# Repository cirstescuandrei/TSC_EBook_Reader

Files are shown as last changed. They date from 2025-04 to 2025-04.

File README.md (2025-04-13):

# TSC_EBook_Reader

### Cîrstescu Andrei-Vlad 331CC

# Tabletă E-Paper ESP32-C6 – Documentație Hardware

## Descriere Generală

Această tabletă cu afișaj E-Paper este proiectată pentru consum redus de energie și uzabilitate extinsă. 
Se bazează pe ESP32-C6 și include funcționalități precum citire din microSD, senzori de mediu, RTC și 
interacțiune cu utilizatorul prin butoane tactile.

openbook_diagram

# BOM
| Components 	| Links 	|
|---	|---	|
| BOOT_BUTTON, RESET_BUTTON, CANGE_BUTTON 	| https://industry.panasonic.com/global/en/products/control/switch/light-touch/number/evqpuj02k 	|
| C1, C1_BAT, C1_BAT1, C1_BAT2, C2, C2_BAT, C4, C4_USB, C5, C6, C7, C8, C9, C10, C_DELAY,  EPD_C1, EPD_C2, EPD_C5, EPD_C6, EPD_C7, EPD_C8, EPD_C9, EPD_C10, EPD_C11, EPD_C12 	| https://componentsearchengine.com/part-view/CC0402MRX5R5BB106/YAGEO 	|
| C3 	| https://componentsearchengine.com/part-view/TCJB107M002R0055E/Kyocera%20AVX 	|
| C10_SUPERCAP 	| https://www.snapeda.com/parts/CPH3225A/Seiko+Instruments/view-part/?ref=eda 	|
| CHG_LED 	| https://www.snapeda.com/parts/KP-1608SURCK/Kingbright/view-part/?ref=search&t=LED%200603 	|
| D1 	| https://www.snapeda.com/parts/USBLC6-2SC6Y/STMicroelectronics/view-part/?ref=eda 	|
| D2, D7 	| https://eu.mouser.com/ProductDetail/KYOCERA-AVX/SD0805S020S1R0?qs=jCA%252BPfw4LHbpkAoSnwrdjw%3D%3D 	|
| D3, D4, D5 	| https://www.snapeda.com/parts/MBR0530/Onsemi/view-part/?ref=eda 	|
| D6, D8, D9, D10, D11, D12 	| https://www.snapeda.com/parts/PGB1010603MR/Littelfuse/view-part/?ref=eda 	|
| IC1 	| https://componentsearchengine.com/part-view/BD5229G-TR/ROHM%20Semiconductor 	|
| IC4 	| https://componentsearchengine.com/part-view/XC6220A331MR-G/Torex 	|
| J1 	| https://www.mouser.co.uk/ProductDetail/Hirose-Connector/FH34SRJ-24S-0.5SH99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 	|
| J2 	| https://componentsearchengine.com/part-view/USB4110-GF-A/GCT%20(GLOBAL%20CONNECTOR%20TECHNOLOGY 	|
| J3 	| https://www.mouser.co.uk/ProductDetail/Adafruit/4208?qs=PzGy0jfpSMtbScLbr0L5dw%3D%3D 	|
| J4 	| https://store.comet.srl.ro/Catalogue/Product/43497/ 	|
| L1 	| https://eu.mouser.com/ProductDetail/Wurth-Elektronik/744043680?qs=PGXP4M47uW6VkZq%252BkzjrHA%3D%3D 	|
| PFMF.050.1 	| https://www.mouser.co.uk/ProductDetail/EPCOS-TDK/B72520T0350K062?qs=dEfas%2FXlABIszF52uu7vrg%3D%3D 	|
| Q1, Q2 	| https://componentsearchengine.com/part-view/DMG2305UX-7/Diodes%20Incorporated 	|
| Q3 	| https://componentsearchengine.com/part-view/SI1308EDL-T1-GE3/Vishay_ 	|
| R1, R1-PINH, R1-PINH1, R1_BAT, R1_PWRUSB, R2, R2-PINH, R2-PINH1, R2-USB, R2-USB1, R2_BAT, R3, R4, R5, R6, R7, R8, R9, 10, R_BOOT, R_CAPACITOR, R_CHANGE, R_CL1, R_RESET 	| https://componentsearchengine.com/part-view/R0402%201%25%20100%20K%20(RC0402FR-07100KL)/YAGEO 	|
| SENSOR2 	| https://www.snapeda.com/parts/BME680/Bosch/view-part/?welcome=home 	|
| SJ1 	| https://grabcad.com/library/solder-jumpers-1 	|
| TP 	| - 	|
| U1 	| https://www.snapeda.com/parts/W25Q512JVEIQ/Winbond+Electronics/view-part/?ref=eda 	|
| U2 	| https://www.snapeda.com/parts/ESP32-C6-WROOM-1-N8/Espressif+Systems/view-part/?ref=eda 	|
| U3 	| https://www.snapeda.com/parts/DS3231SN%23/Analog+Devices/view-part/?ref=eda 	|
| U4 	| https://www.snapeda.com/parts/MAX17048G+T10/Analog+Devices/view-part/?ref=eda 	|
| U5 	| https://www.mouser.co.uk/ProductDetail/Microchip-Technology/MCP73831T-5ACI-OT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 	|

---

## Componente Principale

### ESP32-C6-WROOM-1-N8
- Control total: afișaj, senzori, memorie
- Protocoale: SPI, I²C, UART, USB 2.0
- Consum: ~130 mA activ / ~12 µA deep sleep

### Afișaj E-Paper 7.5” (800x480 px)
- SPI + GPIO: BUSY, DC, RST, CS
- Consum 0 mA idle, ~26 mA la refresh
- Perfect pentru afișare statică de lungă durată

### Memorie
- **W25Q512 NOR Flash** (64MB, SPI) – firmware & cărți
- **MicroSD Card** (SPI partajat) – fișiere externe

### RTC – DS3231SN
- I²C + GPIO (INT, RST)
- Timp real precis, funcțional și în sleep
- Suportă trezirea automată

### Senzor Ambiental – BME680
- Temperatură, umiditate, presiune, compuși volatili
- I²C partajat cu RTC
- Consum redus: ~2.1 mA activ

### Alimentare
- **Baterie Li-Po 2500 mAh**
- **Încărcare USB-C** cu MCP73831 (max 1A)
- **LDO XC6220** – 3.3V stabil pentru sistem
- Monitorizare baterie prin MAX17048 (ADC pe IO18)
- LED încărcare controlat de IO4

### USB-C & Protecție
- Protocol: USB 2.0 + VBUS
- Programare + alimentare
- Protecție ESD integrată

### Interfață Utilizator
- 3 butoane tactile: BOOT (IO15), RESET (IO3), CHANGE (IO23)
- LED stare încărcare (IO4)

### Extensii
- **Qwiic/Stemma QT**: senzori I²C plug & play (IO19/IO20)
- GPIO suplimentari disponibili

---

## Pinout ESP32-C6

| Pin ESP32 | Funcție | Periferic |
|---|---|---|
| IO2 | MISO (SPI) | Flash, SD, E-Paper  |
| IO6 | SCK (SPI) | Flash, SD, E-Paper  |
| IO7 | MOSI (SPI) | Flash, SD, E-Paper  |
| IO12 | CS Flash | Memorie NOR |
| IO10 | CS E-Paper | Display |
| IO4 | CS SD | microSD |
| IO5 | DC E-Paper | Display |
| IO14 | BUSY E-Paper  | Display |
| IO21 | RST E-Paper | Display |
| IO19/20 | SDA/SCL (I²C) | RTC, BME680, Qwiic  |
| IO0 | INT RTC | RTC Wake |
| IO17 | RTC RST | RTC Reset |
| IO18 | ADC Battery | Monitorizare |
| IO15 | BOOT | Buton BOOT |
| IO3 | RESET | Buton RESET |
| IO23 | CHANGE | Buton navigare |
| IO25/24 | UART TX/RX | Debug Serial |

---

## Estimare Consum

| Modul | Activ | Idle / Sleep |
|---|---|---|
| ESP32-C6 | ~130 mA | ~12 µA |
| E-Paper | ~26 mA | 0 mA |
| BME680 | ~2.1 mA | 0.15 mA |
| microSD | 30–100 mA | ~0.1 mA |
| RTC | ~1 µA | - |
| LED | max 10 mA | - |

### Durată estimată cu baterie 2500 mAh
- Utilizare activă: **8–10 ore**
- Standby / Deep sleep: **până la 300 zile**

---

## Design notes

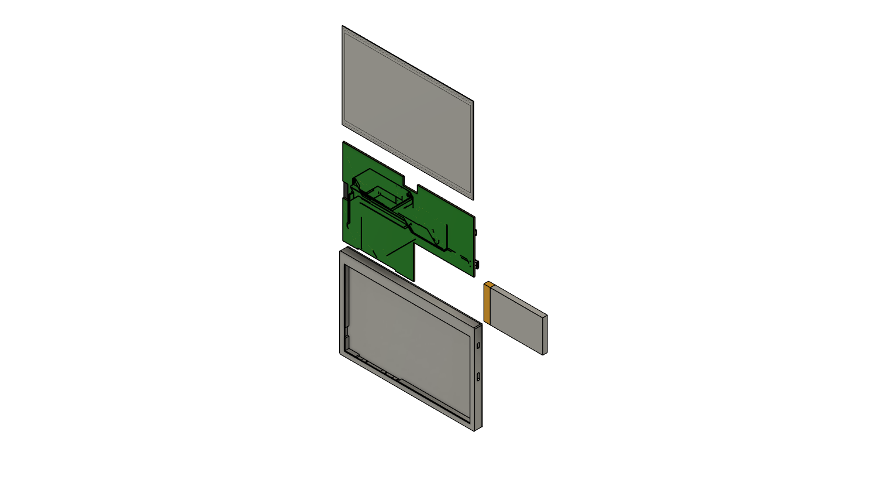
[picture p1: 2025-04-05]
Images/OpenBook_3D_Model_Exploded.png

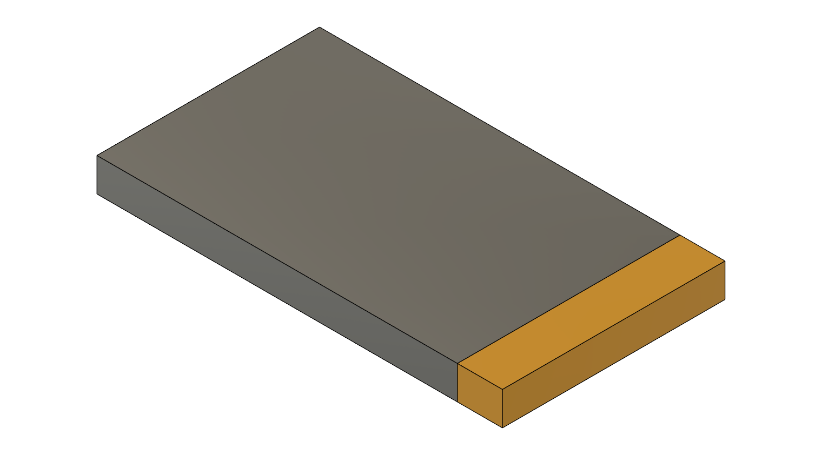
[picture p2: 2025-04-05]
Images/Battery.png

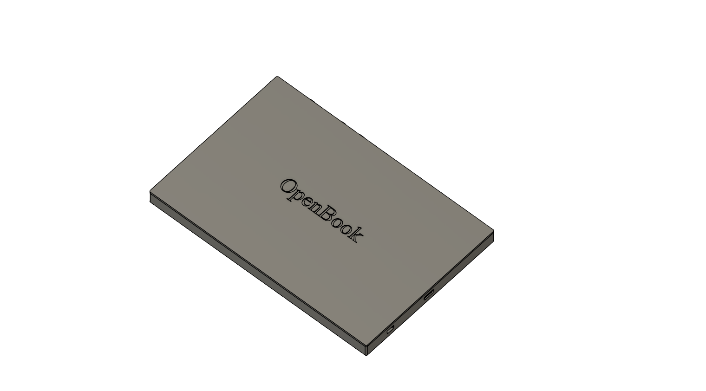
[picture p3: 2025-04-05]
Images/OpenBook_3D_Model.png

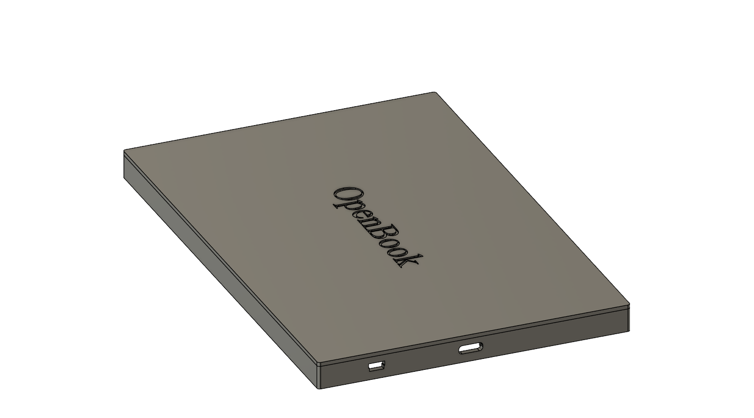
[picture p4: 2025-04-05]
Images/OpenBook Enclosure.png

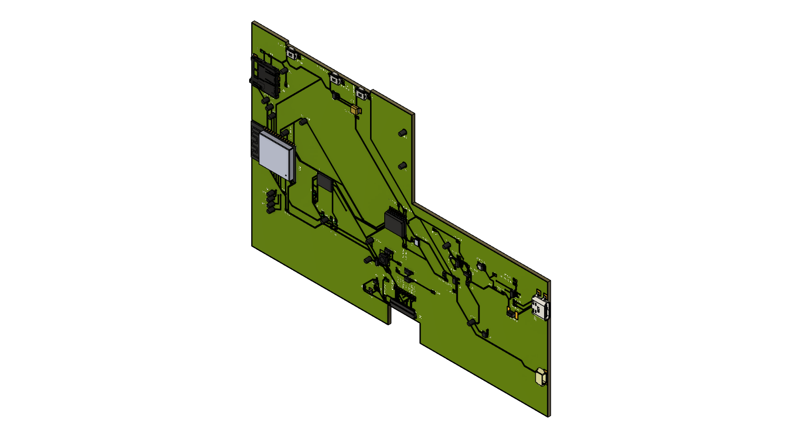
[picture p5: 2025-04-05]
Images/PCB.png

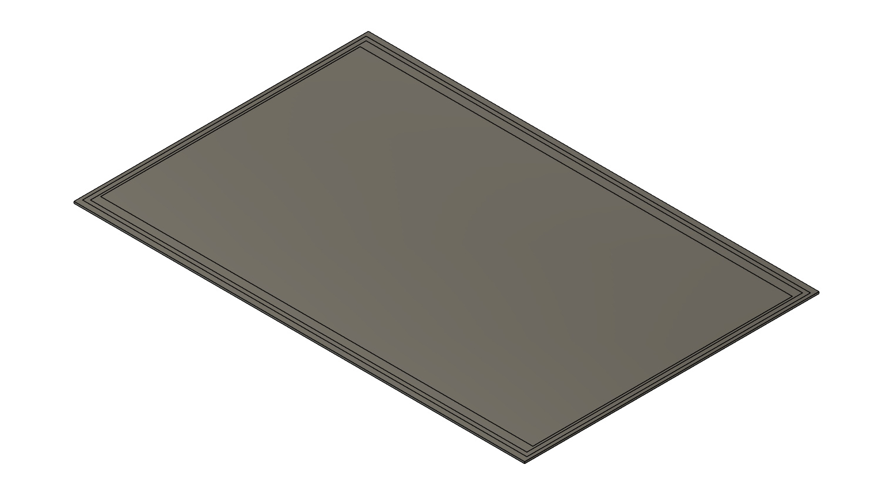
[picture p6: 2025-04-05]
Images/Display.png

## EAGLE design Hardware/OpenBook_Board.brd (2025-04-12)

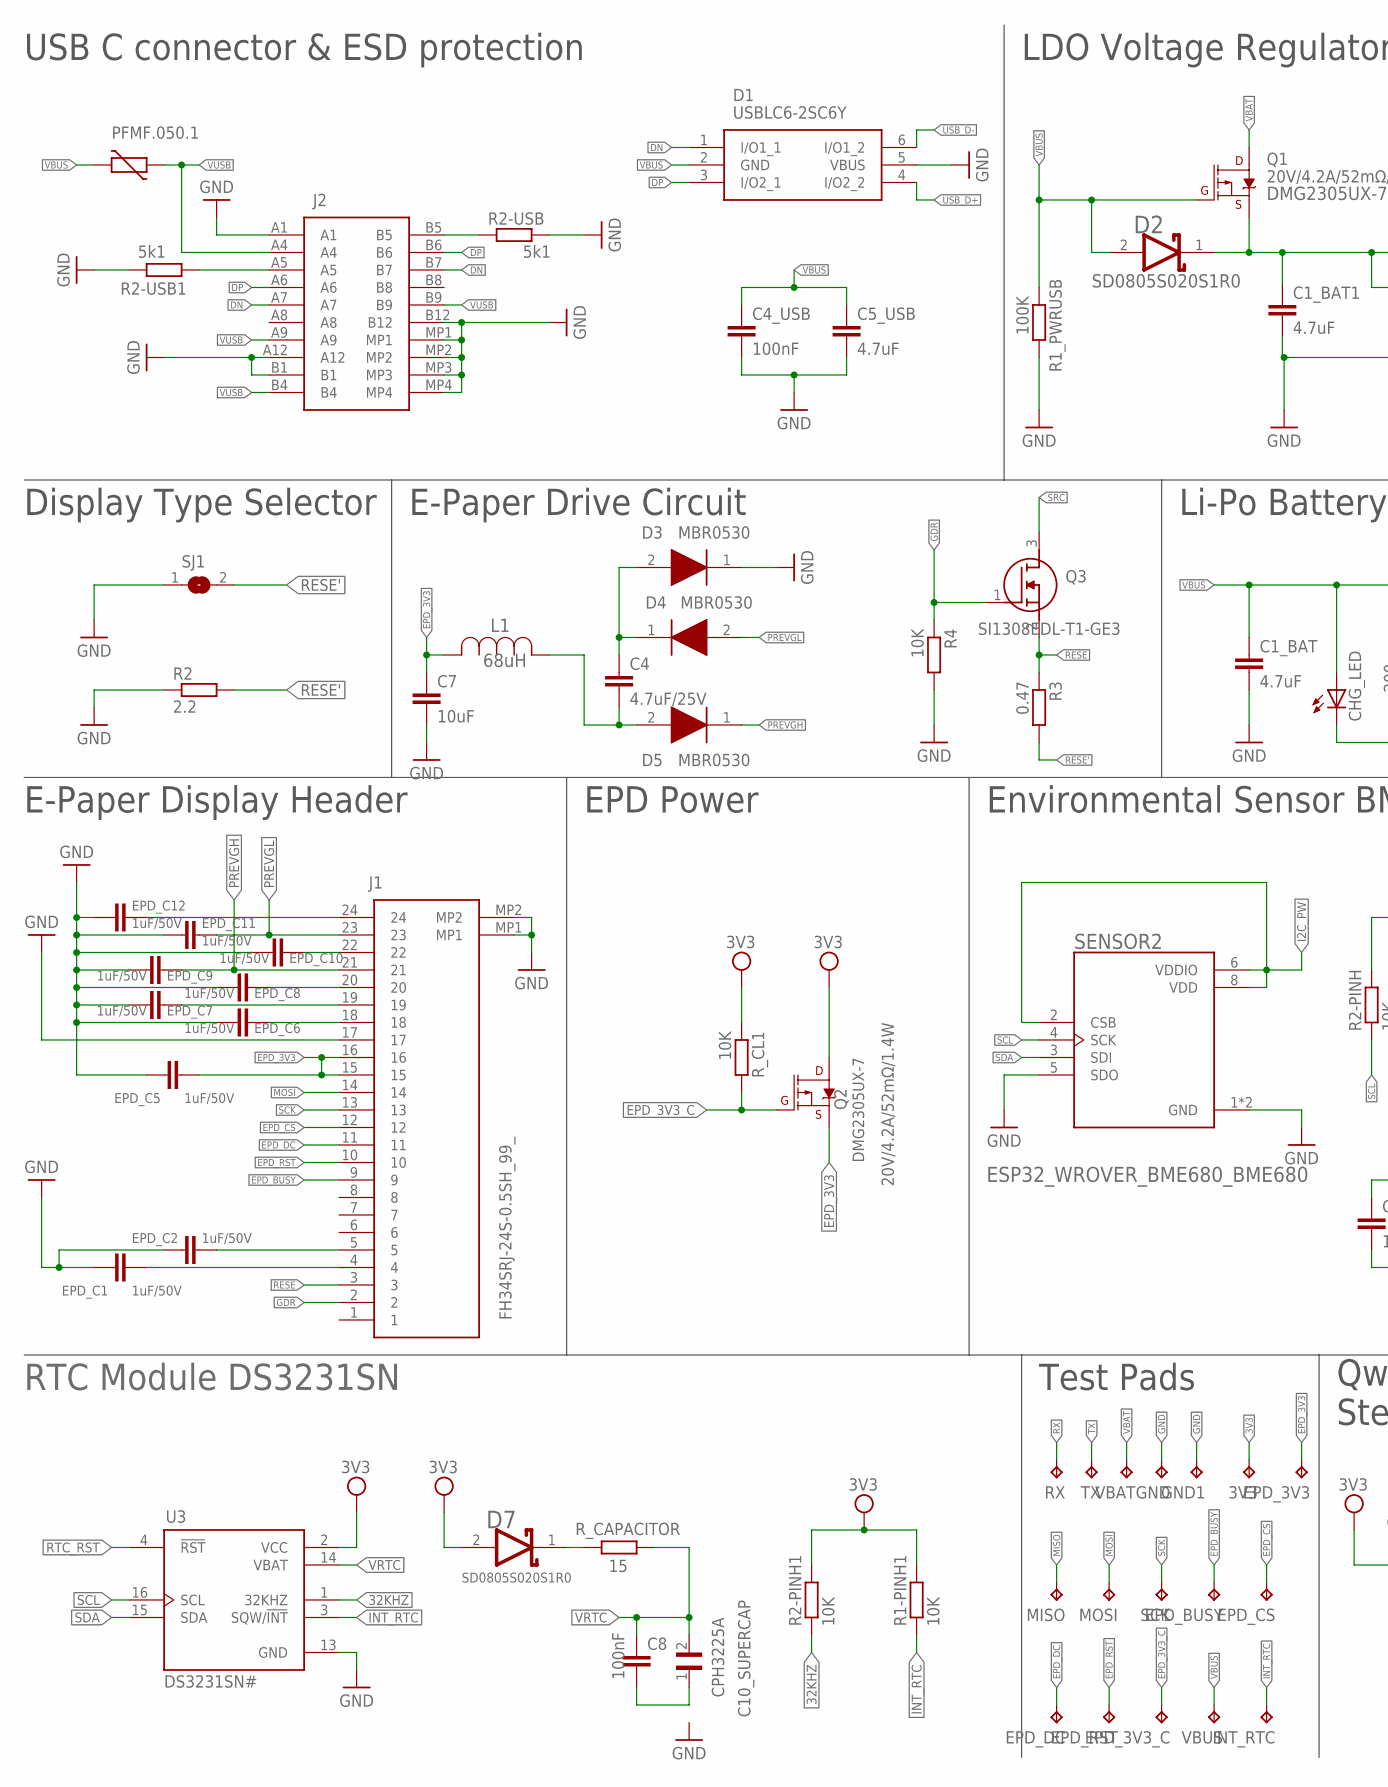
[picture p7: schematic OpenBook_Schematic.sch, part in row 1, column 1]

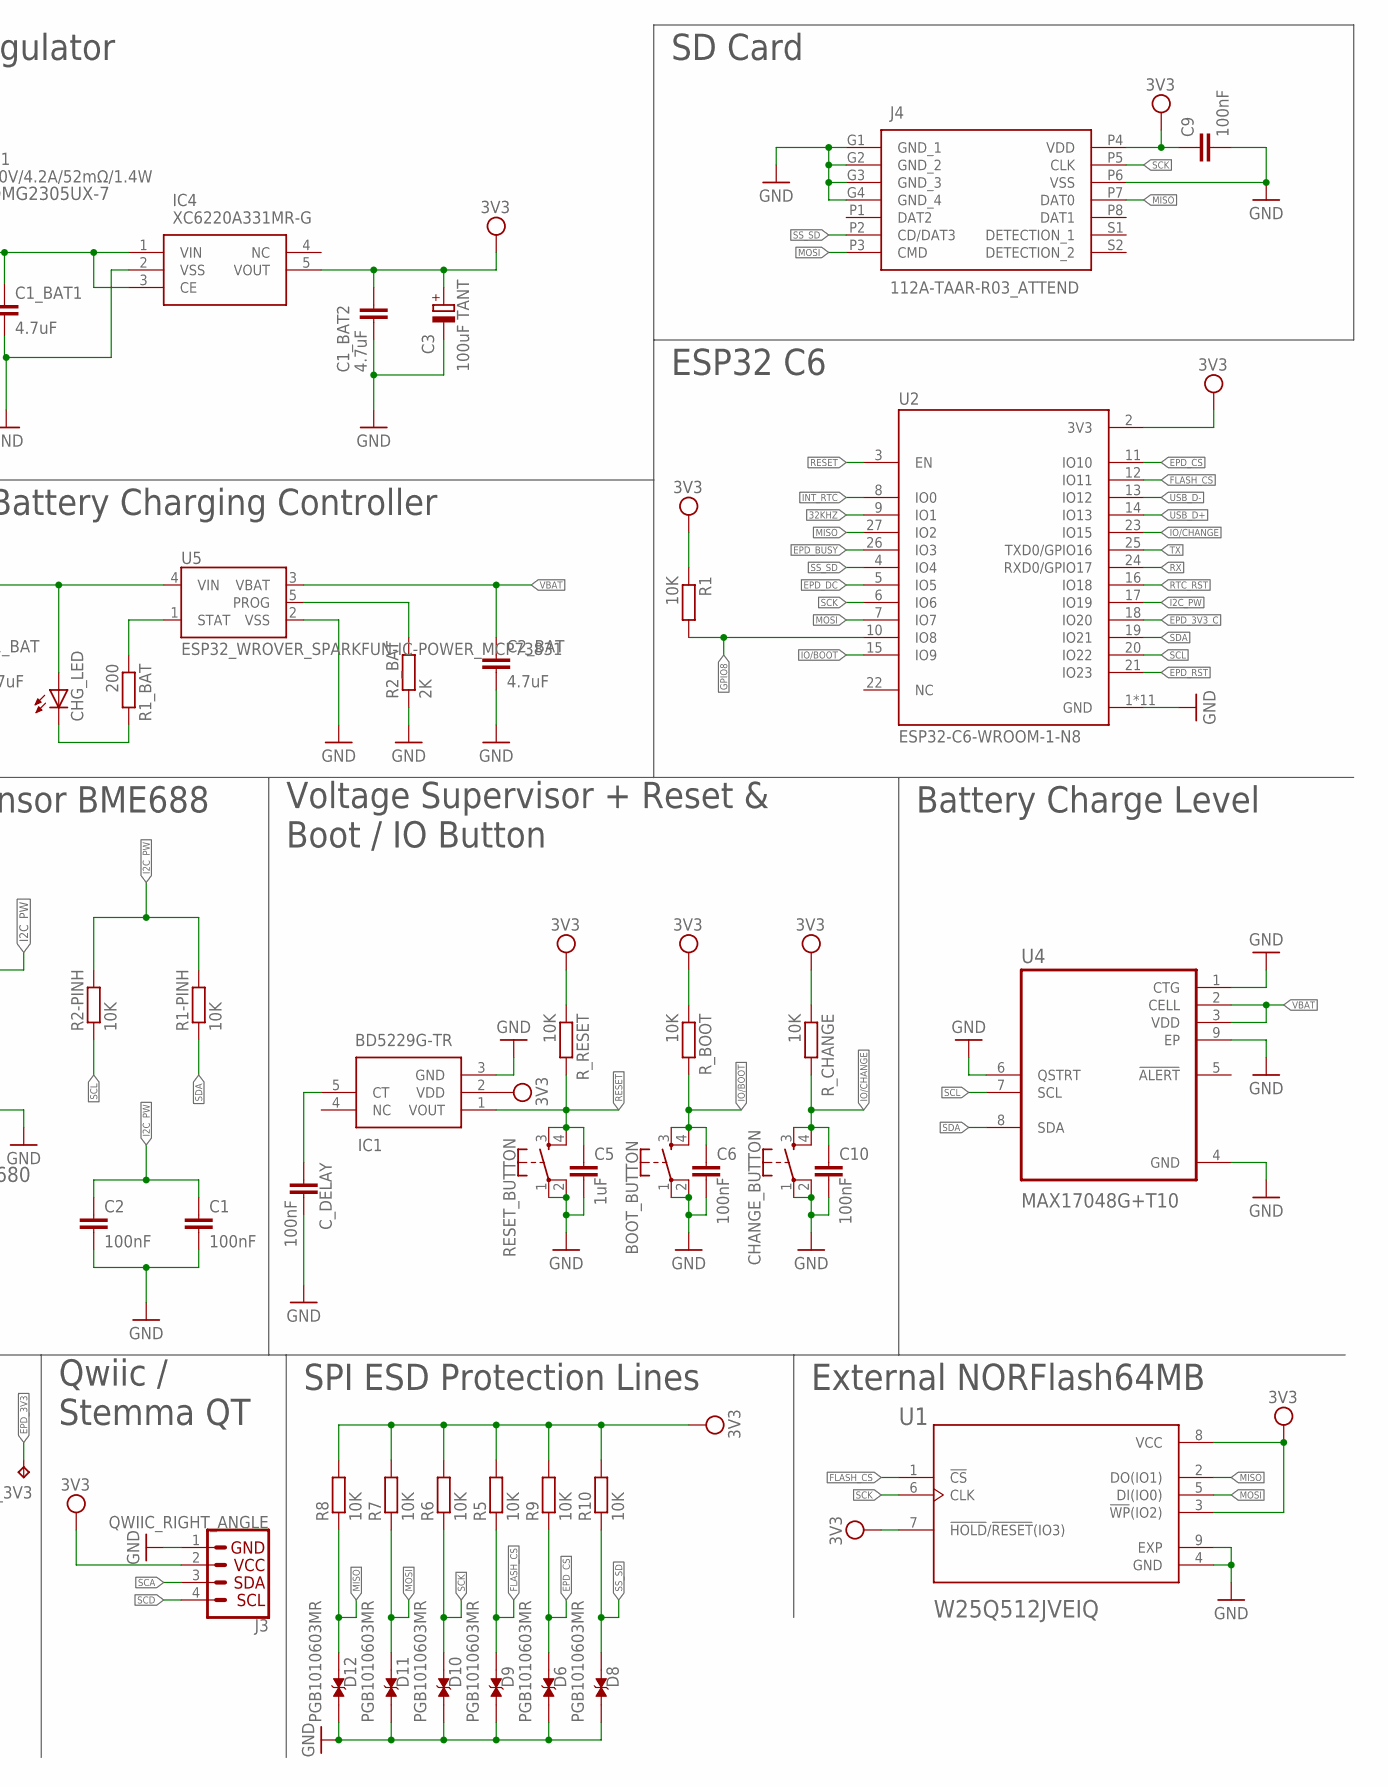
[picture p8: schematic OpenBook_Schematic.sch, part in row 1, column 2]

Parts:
3V3: TPTP20R; TP20R
BOOT_BUTTON: BUTTON_CUSYOMV1BUTTON; MYBUTTON
C1, C2, C9: 100nF; ESP32_WROVER_EAGLE-LTSPICE_C0402
C1_BAT, C1_BAT1, C1_BAT2, C2_BAT, C5_USB: 4.7uF; EAGLE-LTSPICE_C0402
C3: 100uF TANT; RCL_CT3528
C4: 4.7uF/25V; EAGLE-LTSPICE_C0402
C4_USB, C6, C8, C10: 100nF; EAGLE-LTSPICE_C0402
C5: 1uF; EAGLE-LTSPICE_C0402
C7: 10uF; EAGLE-LTSPICE_C0402
C10_SUPERCAP: CPH3225A; CAPCP3225X100N
CHANGE_BUTTON: BUTTON_CUSYOMV1BUTTON; MYBUTTON
CHG_LED: ADAFRUIT_LEDCHIP-LED0603; ADAFRUIT_CHIP-LED0603
C_DELAY: 100nF; ESP32_WROVER_EAGLE-LTSPICE_C0402
D1: USBLC6-2SC6Y; SOT95P280X145-6N
D2, D7: ESP32_WROVER_AVX---SD0805S020S1R0_AVX_SD0805S020S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; ESP32_WROVER_AVX---SD0805S020S1R0_AVX_SD0805S020S1R0_0
D3, D4, D5: MBR0530; SOD3716X135N
D6, D8, D9, D10, D11, D12: PGB1010603MR; DIOC1608X36N
EPD_3V3, EPD_3V3_C: TPTP20R; TP20R
EPD_BUSY: TPTP20R; TP20R
EPD_C1, EPD_C2, EPD_C5, EPD_C6, EPD_C7, EPD_C8, EPD_C9, EPD_C10, EPD_C11, EPD_C12: 1uF/50V; ESP32_WROVER_EAGLE-LTSPICE_C0402
EPD_CS: TPTP20R; TP20R
EPD_DC: TPTP20R; TP20R
EPD_RST: TPTP20R; TP20R
GND, GND1: TPTP20R; TP20R
IC1: BD5229G-TR; SOT95P280X125-5N
IC4: XC6220A331MR-G; SOT95P280X120-5N
INT_RTC: TPTP20R; TP20R
J1: FH34SRJ-24S-0.5SH_99_; FH34SRJ24S05SH99
J2: SAMACSYS_PARTS_USB4110-GF-A; SAMACSYS_PARTS_USB4110GFA
J3: QWIIC_RIGHT_ANGLE; JST04_1MM_RA
J4: 112A-TAAR-R03_ATTEND; 112ATAARR03ATTEND
L1: 68uH; IND_4828-WE-TPC_WRE
MISO: TPTP20R; TP20R
MOSI: TPTP20R; TP20R
PFMF.050.1: ESP32C6_VARISTORCN1812; ESP32C6_VARISTOR_CT/CN1812
Q1, Q2: 20V/4.2A/52mΩ/1.4W; ESP32_WROVER_SPARKFUN-DISCRETESEMI_SOT23-3
Q3: SI1308EDL-T1-GE3; SOT65P210X110-3N
R1, R1-PINH, R1-PINH1, R2-PINH, R2-PINH1, R4, R5, R6, R7, R8, R9, R10: 10K; ESP32_WROVER_EAGLE-LTSPICE_R0402
R1_BAT: 200; ESP32_WROVER_EAGLE-LTSPICE_R0402
R1_PWRUSB: 100K; ESP32_WROVER_EAGLE-LTSPICE_R0402
R2: 2.2; ESP32_WROVER_EAGLE-LTSPICE_R0402
R2-USB, R2-USB1: 5k1; ESP32_WROVER_EAGLE-LTSPICE_R0402
R2_BAT: 2K; ESP32_WROVER_EAGLE-LTSPICE_R0402
R3: 0.47; ESP32_WROVER_EAGLE-LTSPICE_R0402
RESET_BUTTON: BUTTON_CUSYOMV1BUTTON; MYBUTTON
RX: TPTP20R; TP20R
R_BOOT: 10K; ESP32_WROVER_EAGLE-LTSPICE_R0402
R_CAPACITOR: 15; ESP32_WROVER_EAGLE-LTSPICE_R0402
R_CHANGE: 10K; ESP32_WROVER_EAGLE-LTSPICE_R0402
R_CL1: 10K; ESP32_WROVER_EAGLE-LTSPICE_R0402
R_RESET: 10K; ESP32_WROVER_EAGLE-LTSPICE_R0402
SCK: TPTP20R; TP20R
SENSOR2: ESP32_WROVER_BME680_BME680; ESP32_WROVER_BME680_PSON80P300X300X100-8N
SJ1: SJ
TX: TPTP20R; TP20R
U1: W25Q512JVEIQ; SON127P600X800X80-9N
U2: ESP32-C6-WROOM-1-N8; XCVR_ESP32-C6-WROOM-1-N8
U3: DS3231SN#; SOIC127P1032X265-16N
U4: MAX17048G+T10; SON50P200X200X80-9N
U5: ESP32_WROVER_SPARKFUN-IC-POWER_MCP73831; ESP32_WROVER_SPARKFUN-IC-POWER_SOT23-5
VBAT: TPTP20R; TP20R
VBUS: TPTP20R; TP20R

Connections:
3V3: 3V3.TP, C1_BAT2.1, C3.+, C9.1, D7.2 (ANODE), IC1.2 (VDD), IC4.5 (VOUT), J3.2, J4.P4 (VDD), Q2.3 (D), R1.1, R1-PINH1.2, R2-PINH1.2, R5.2, R6.2, R7.2, R8.2, R9.2, R10.2, R_BOOT.1, R_CHANGE.1, R_CL1.1, R_RESET.1, U1.3 (!WP!(IO2)), U1.7 (!HOLD!/!RESET!(IO3)), U1.8 (VCC), U2.2 (3V3), U3.2 (VCC)
32KHZ: R2-PINH1.1, U2.9 (IO1), U3.1 (32KHZ)
DN: D1.1 (I/O1_1), J2.A7, J2.B7
DP: D1.3 (I/O2_1), J2.A6, J2.B6
EPD_3V3: C7.1, EPD_3V3.TP, EPD_C5.1, J1.15, J1.16, L1.2, Q2.2 (S)
EPD_3V3_C: EPD_3V3_C.TP, Q2.1 (G), R_CL1.2, U2.18 (IO20)
EPD_BUSY: EPD_BUSY.TP, J1.9, U2.26 (IO3)
EPD_CS: D6.2, EPD_CS.TP, J1.12, R9.1, U2.11 (IO10)
EPD_DC: EPD_DC.TP, J1.11, U2.5 (IO5)
EPD_RST: EPD_RST.TP, J1.10, U2.21 (IO23)
FLASH_CS: D9.2, R5.1, U1.1 (!CS), U2.12 (IO11)
GDR: J1.2, Q3.1 (G), R4.1
GND: BOOT_BUTTON.1, BOOT_BUTTON.2, C1.2, C1_BAT.2, C1_BAT1.2, C1_BAT2.2, C2.2, C2_BAT.2, C3.-, C4_USB.2, C5.2, C5_USB.2, C6.2, C7.2, C9.2, C10.2, CHANGE_BUTTON.1, CHANGE_BUTTON.2, C_DELAY.2, D1.5 (VBUS), D3.1 (K), D6.1, D8.1, D9.1, D10.1, D11.1, D12.1, EPD_C1.2, EPD_C2.2, EPD_C5.2, EPD_C6.2, EPD_C7.2, EPD_C8.2, EPD_C9.2, EPD_C10.2, EPD_C11.2, EPD_C12.2, GND.TP, GND1.TP, IC1.3 (GND), IC4.2 (VSS), J1.17, J1.MP1, J1.MP2, J2.A1, J2.A12, J2.B1, J2.B12, J2.MP1, J2.MP2, J2.MP3, J2.MP4, J3.1, J4.G1 (GND_1), J4.G2 (GND_2), J4.G3 (GND_3), J4.G4 (GND_4), J4.P6 (VSS), R1_PWRUSB.2, R2.1, R2-USB.2, R2-USB1.1, R2_BAT.1, R4.2, RESET_BUTTON.1, RESET_BUTTON.2, SENSOR2.1 (GND), SENSOR2.5 (SDO), SENSOR2.7 (GND), SJ1.1, U1.4 (GND), U1.9 (EXP), U2.1 (GND), U2.28 (GND), U2.29_1 (GND), U2.29_2 (GND), U2.29_3 (GND), U2.29_4 (GND), U2.29_5 (GND), U2.29_6 (GND), U2.29_7 (GND), U2.29_8 (GND), U2.29_9 (GND), U3.13 (GND), U4.1 (CTG), U4.4 (GND), U4.6 (QSTRT), U4.9 (EP), U5.2 (VSS)
GPIO8: R1.2, U2.10 (IO8)
I2C_PW: C1.1, C2.1, R1-PINH.2, R2-PINH.2, SENSOR2.2 (CSB), SENSOR2.6 (VDDIO), SENSOR2.8 (VDD), U2.17 (IO19)
INT_RTC: INT_RTC.TP, R1-PINH1.1, U2.8 (IO0), U3.3 (SQW/!INT)
IO/BOOT: BOOT_BUTTON.3, BOOT_BUTTON.4, C6.1, R_BOOT.2, U2.15 (IO9)
IO/CHANGE: C10.1, CHANGE_BUTTON.3, CHANGE_BUTTON.4, R_CHANGE.2, U2.23 (IO15)
MISO: D12.2, J4.P7 (DAT0), MISO.TP, R8.1, U1.2 (DO(IO1)), U2.27 (IO2)
MOSI: D11.2, J1.14, J4.P3 (CMD), MOSI.TP, R7.1, U1.5 (DI(IO0)), U2.7 (IO7)
unnamed: D7.1 (CATHODE), R_CAPACITOR.2
unnamed: EPD_C2.1, J1.5
unnamed: C8.2, C10_SUPERCAP.1
unnamed: EPD_C1.1, J1.4
unnamed: EPD_C6.1, J1.18
unnamed: EPD_C7.1, J1.19
unnamed: C_DELAY.1, IC1.5 (CT)
unnamed: C4.2, D5.2 (A), L1.1
unnamed: EPD_C8.1, J1.20
unnamed: C4.1, D3.2 (A), D4.1 (K)
unnamed: EPD_C10.1, J1.22
unnamed: EPD_C12.1, J1.24
unnamed: CHG_LED.C, R1_BAT.2
unnamed: R1_BAT.1, U5.1 (STAT)
unnamed: R2_BAT.2, U5.5 (PROG)
unnamed: C1_BAT1.1, D2.1 (CATHODE), IC4.1 (VIN), IC4.3 (CE), Q1.2 (S)
unnamed: J2.A5, R2-USB1.2
unnamed: J2.B5, R2-USB.1
PREVGH: D5.1 (K), EPD_C9.1, J1.21
PREVGL: D4.2 (A), EPD_C11.1, J1.23
RESE: J1.3, Q3.2 (S), R3.1
RESE': R2.2, R3.2, SJ1.2
RESET: C5.1, IC1.1 (VOUT), RESET_BUTTON.3, RESET_BUTTON.4, R_RESET.2, U2.3 (EN)
RTC_RST: U2.16 (IO18), U3.4 (!RST)
RX: RX.TP, U2.24 (RXD0/GPIO17)
SCA: J3.3
SCD: J3.4
SCK: D10.2, J1.13, J4.P5 (CLK), R6.1, SCK.TP, U1.6 (CLK), U2.6 (IO6)
SCL: R2-PINH.1, SENSOR2.4 (SCK), U2.20 (IO22), U3.16 (SCL), U4.7 (SCL)
SDA: R1-PINH.1, SENSOR2.3 (SDI), U2.19 (IO21), U3.15 (SDA), U4.8 (SDA)
SRC: Q3.3 (D)
SS_SD: D8.2, J4.P2 (CD/DAT3), R10.1, U2.4 (IO4)
TX: TX.TP, U2.25 (TXD0/GPIO16)
USB_D+: D1.4 (I/O2_2), U2.14 (IO13)
USB_D-: D1.6 (I/O1_2), U2.13 (IO12)
VBAT: C2_BAT.1, Q1.3 (D), U4.2 (CELL), U4.3 (VDD), U5.3 (VBAT), VBAT.TP
VBUS: C1_BAT.1, C4_USB.1, C5_USB.1, CHG_LED.A, D1.2 (GND), D2.2 (ANODE), PFMF.050.1.2, Q1.1 (G), R1_PWRUSB.1, U5.4 (VIN), VBUS.TP
VRTC: C8.1, C10_SUPERCAP.2, R_CAPACITOR.1, U3.14 (VBAT)
VUSB: J2.A4, J2.A9, J2.B4, J2.B9, PFMF.050.1.1

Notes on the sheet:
SD0805S020S1R0
RTC Module DS3231SN
Test Pads
Qwiic / Stemma QT
SPI ESD Protection Lines
External NORFlash64MB
EPD Power
DMG2305UX-7
E-Paper Display Header
Environmental Sensor BME688
Voltage Supervisor + Reset & Boot / IO Button
Battery Charge Level
Display Type Selector
E-Paper Drive Circuit
Li-Po Battery Charging Controller
ESP32 C6
SD Card
LDO Voltage Regulator
USB C connector & ESD protection

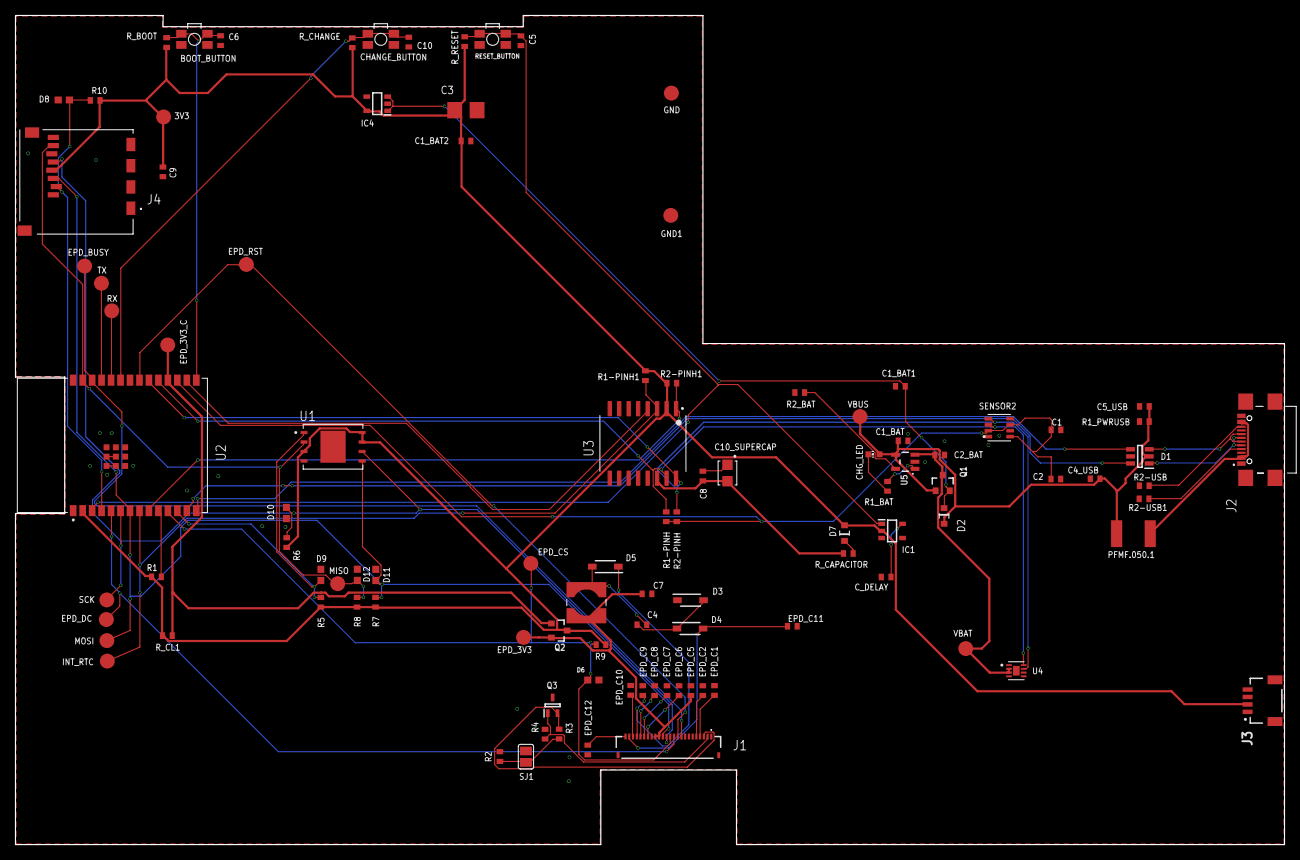
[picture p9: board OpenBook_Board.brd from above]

Board: 2 copper layers, 170.2 x 111.2 mm, 103 parts (0 on the bottom side), 56 nets.

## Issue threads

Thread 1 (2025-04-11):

Lipsa README

iza03, 2025-04-11:
Impact:

Lipsa documentației îngreunează înțelegerea arhitecturii și a deciziilor de design hardware.

Nu se respectă cerințele din DVT/Go-No-Go → scădere punctaj.

Soluție propusă: Adăugarea unui README.md care să conțină:

Diagrama bloc a sistemului

Tabel cu BOM complet, linkuri achiziție + datasheet

Funcționalități hardware

Conexiuni GPIO

Estimare consum

Randări / imagini PCB

Closed 2025-04-13.

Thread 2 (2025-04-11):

Trasee GND multiple

iza03, 2025-04-11:
Descriere:
În layout-ul PCB sunt trasee dedicate pentru GND, deși există deja un plan de masă definit.

Impact:

- Poate apărea zgomot în alimentare (buclă de masă).
- Se reduce eficiența planului de masă.
- Nerespectarea bunelor practici de layout pentru semnal și putere.

Soluție:

- Elimină traseele de GND redundante și conectează nodurile GND doar la planul de masă.
- Verifică dacă polygon pour-ul acoperă complet toate punctele de GND.
- Aplică via stitching, mai ales în jurul ESP32.

Closed 2025-04-12.

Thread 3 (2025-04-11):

Grosime PCB

iza03, 2025-04-11:
Impact:

- PCB-ul nu încape în carcasa proiectată.
- Poate duce la poziționare incorectă a conectorilor și componentelor.

Soluție:

- În Fusion360, accesează Layer Stack Manager și modifică grosimea plăcii la 1 mm.
- Verifică compatibilitatea mecanică cu modelul 3D al carcasei.

Closed 2025-04-12.

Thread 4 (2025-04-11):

Linii de măsurători pe layer greșit

iza03, 2025-04-11:
În fișierul 2D PCB (layout), liniile de contur sau măsurători care definesc dimensiunile plăcii și amplasarea componentelor nu sunt desenate pe layer-ul dedicat (Measurments), ci pe alt layer.

Impact:

- Poate duce la interpretări greșite în procesul de fabricație.
- DRC/Verificările de layout pot da erori false sau pot ignora aceste margini.
- Exportul către producător (Gerber/STEP) poate omite aceste contururi.

Soluție:

- Muta liniile de măsurători pe layer-ul corect (Measurments) în Fusion360.
- Confirmă că layer-ul este activat în fișierul Gerber.
- Asigură-te că dimensiunile sunt vizibile și clare pentru review tehnic.

Closed 2025-04-12.

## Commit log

2025-04-05 Added Project Files
    [OpenBook_Board.brd, OpenBook_Schematic.sch]
2025-04-12 Added final Board
    Fixed measure layer issues, reduced PCB thickness to 1mm and removed unnecessary GND traces
    [OpenBook_Board.brd]
2025-04-12 Added redone gerbers

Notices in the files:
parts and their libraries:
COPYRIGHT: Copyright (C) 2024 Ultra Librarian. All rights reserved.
